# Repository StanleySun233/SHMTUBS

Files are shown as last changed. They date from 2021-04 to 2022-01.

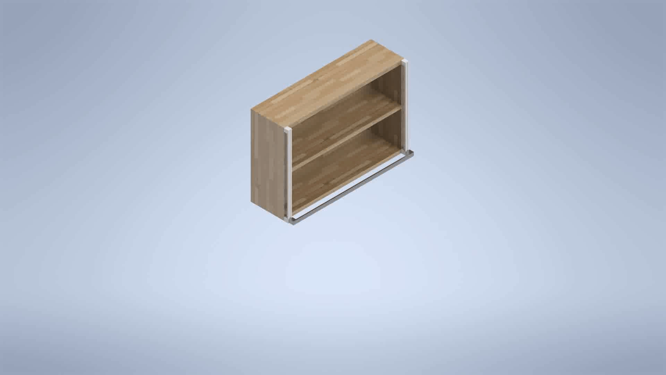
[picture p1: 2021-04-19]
3D-construction/视频/滑台移动.gif

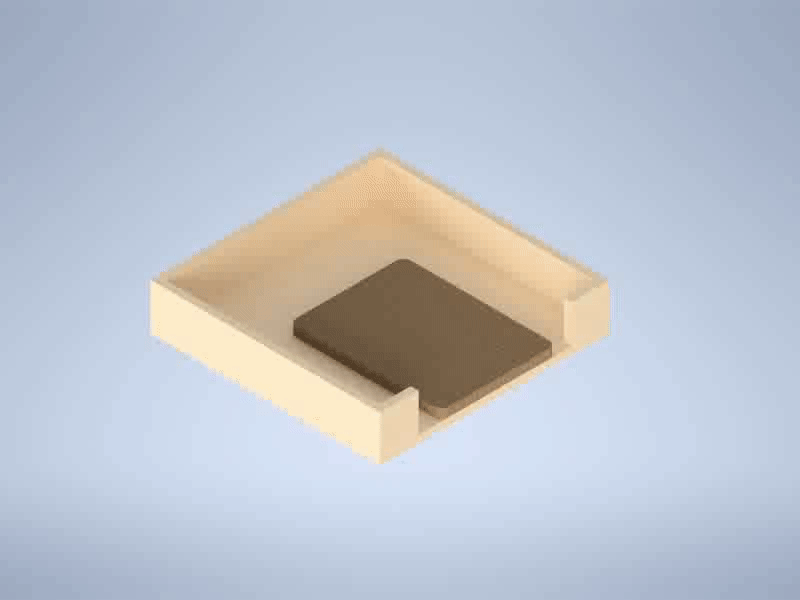
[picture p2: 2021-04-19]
3D-construction/视频/书本直立.gif

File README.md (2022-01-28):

# Robot For Book Sorting

## 简介

这个项目的代码起始于2021年度大学生创新创业训练计划项目。

## 主体

1. 将书本堆放在机器人上，重力感应器激活，进入工作状态。

2. 摄像头识别最上面的一本书。

3. 摄像头模块的单片机识别并转换条形码，输入到单片机主控。

4. WiFi模块连接到图书馆数据库，查找该条形码对应的图书所在的位置。

5. 找到相应的位置后，服务器传出位置信息，WiFi模块接受收数据。

6. 机械臂抓取最上面的图书，放到牵引臂上。

7. 横轴步进电机根据传回数据，向右运行厘米。

8. 纵轴步进电机根据传回数据，向上运行厘米。

9. 牵引臂推动图书进入指定位置。

10. 牵引臂返回到初始位置，重复运行程序，直至重力传感器检测到没有书籍。

## 寻迹：

1. 利用红外传感器，识别地面贴黑条区域和普通地面区域，黑色用1表示，普通地面用0表示。

2. 默认机器人初始在黑条区域，机器人前后左右配备四个红外传感器。

3. 如果单位时间监测区域均为1，那么传回信号，驱动小车直接向前走。

4. 如果单位时间某个方向的检测区不为1，那么通过算法设计传回信号，驱动小车转弯或者回退等操作。

## 涉及语言：C Python

涉及软件：`Arduino` , `Visual Studio` , `Pycharm`

## 参考

1. 循迹小车发布于 `BiliBili` 。

```
https://www.bilibili.com/video/BV1hm4y1Q77d/
```

2. 书本封面来自于开源数据集 `Book-30` 。

```
https://github.com/uchidalab/book-dataset
```

3. 机器学习来源于文章 `An evidential classifier based on Dempster-Shafer theory and deep learning` 的思路。

*目前暂未使用到 `Dempster-Shafer` ，准确率在83%*

```
https://github.com/tongzheng1992/E-CNN-classifier
```

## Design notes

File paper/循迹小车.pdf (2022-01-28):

学号：202010311229

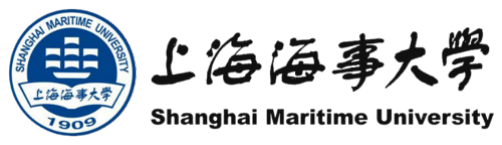
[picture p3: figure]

# 《计算机硬件课程设计》报告

学 | 院： 信息工程学院

专 业 名 称： 计算机科学与技术

班 | 级： 计算机 203
姓 | 名： 孙思进

指 导 教 师： 张琳

## 2021 年 12 月 23 日

《计算机硬件》课程设计报告

摘 要

为研究设计智能寻迹避障小车的控制部分, 文中通过研究超声波模块, 红外线

模块完成小车的控制。首先通过 Arduino 平台以及 Arduino IDE 软件进行程序编程

来控制小车的行驶。

寻迹小车由 MSP430 单片机模块、升压模块、电机驱动模块、红外光电传感器

等部分组成。小车能够沿着地面上的长宽为 1 cm 的黑白相间方格行驶, 并且可以

根据方格路径实现小车的自动寻迹功能, 小车在转弯处可自动减慢速度, 以避免由

于速度过快而偏离给定路线。当红外光电传感器阵列遇到长度为 5 cm, 宽度为 1cm

的黑色条纹的时候, 小车停车。

经过实验测试, 该自动寻迹小车能够较好的实现寻迹功能, 可被用在货物运输、

实验教学和玩具中。

关键词: 寻迹小车; 红外线; 单片机

Key words: Trace trolley; Infrared; Microcontroller

I

目 | 录
摘要 | I
1 任务安排 | 1
2 相关硬件说明 | 2
3 小车结构与系统模块设计 | 7
4 硬件电路设计 | 8
5 工作原理 | 9

II

6 测试 | 14
7 困难及解决方案 | 16

III

## 1 任务安排

表 1.1 人员任务安排

任务安排 | 人员

核心代码 孙思进、肖茗怡

图片视频 | 肖茗怡
代码优化 | 涂枭
文档编写 | 杨怡林、涂枭

## 2 相关硬件说明

### 2.1 Arduino 单片机

### 2.1.1 Arduino Uno 介绍

我们小组的 Arduino 的版本使用的是 Uno，Arduino Uno 是 ArduinoUSB 接 口系列的最新版本，作为 Arduino 平台的参考标准模板。UNO 的处理器核心是 ATmega328，同时具有 14 路数字输入/输出口（其中 6 路可作为 PWM 输出），6 路 模拟输入，一个 16MHz 晶体振荡器，一个 USB 口，一个电源插座，一个 ICSPheader 和一个复位按钮。

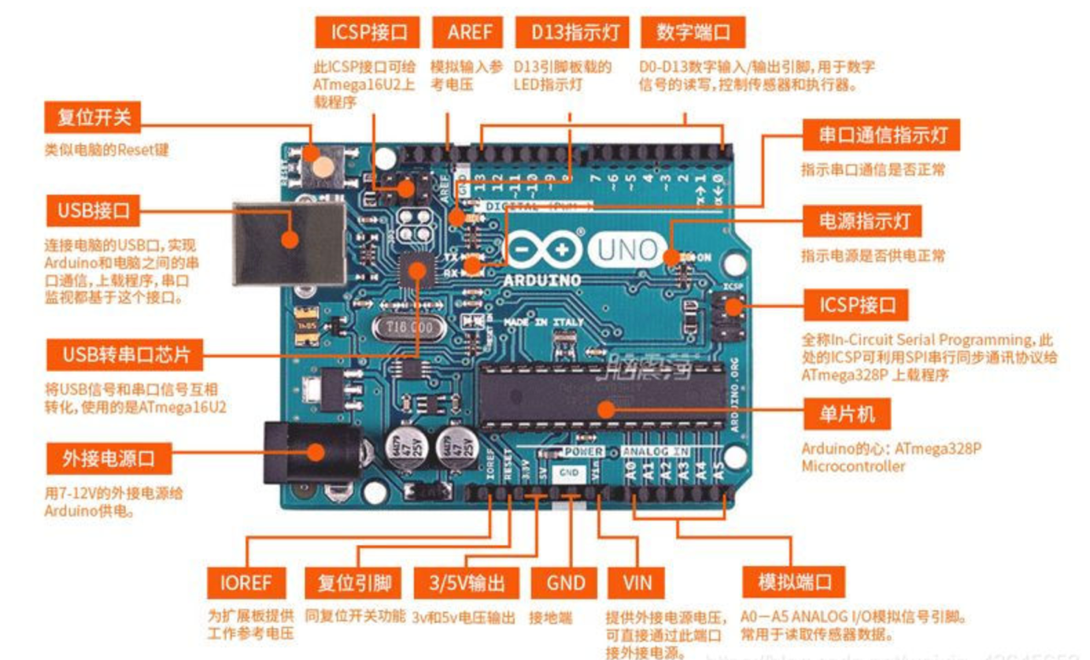
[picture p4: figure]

图 2.1 Arduino Uno 开发板

### 2.1.2 引脚介绍

- Power 引脚：开发板可提供 3.3V 和 5V 电压输出。
- Vin 引脚：可用于从外部电源为开发板供电。
- Analog In 引脚：模拟输入引脚，开发板可读取外部模拟信号，A0 A5 为模拟 输入引脚。
- Digital 引脚：UNO R3 拥有 14 个数字 I/O 引脚，其中 6 个可用于 PWM(脉宽 调制) 输出。

- TX 和 RX 引脚：标有 TX(发送) 和 RX(接收) 的两个引脚用于串口通讯。其中 标有 TX 和 RX 的 LED 灯连接相应引脚，在串口通讯时会以不同速度闪烁。
- 13 引脚：开发板标记第 13 引脚，连接板载 LED 灯，可通过控制 13 引脚来控 制 LED 灯亮灭。一般拿到开发板上电板载灯都会闪烁，可辅助检测开发板是 否正常。
- GND：在该项目中 GND 即为电源的负极，同时要保证 Arduino 开发板，驱动 模块等所有模块的 GND 连在一起才可以正常工作。

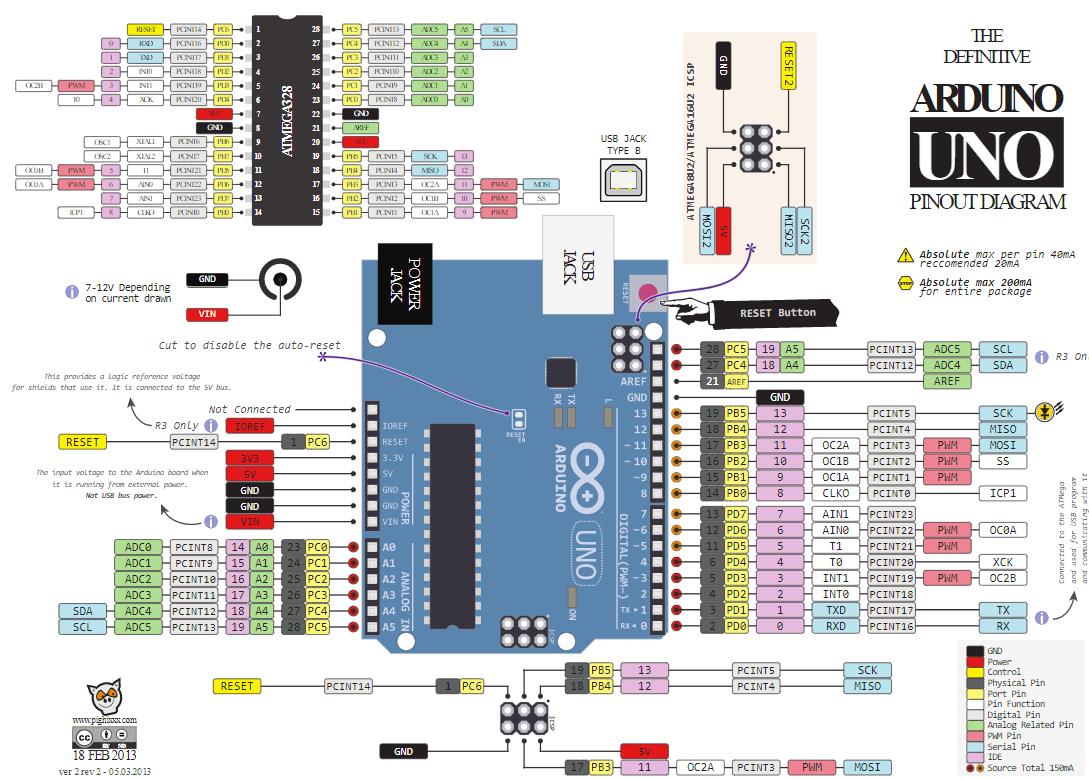
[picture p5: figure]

图 2.2 Arduino Uno 引脚分配图

### 2.1.3 端口介绍

Arduino Uno 有 6 个模拟引脚，它们作为 ADC（模数转换器）使用。这些引脚 用作模拟输入，但也可用作数字输入或数字输出。

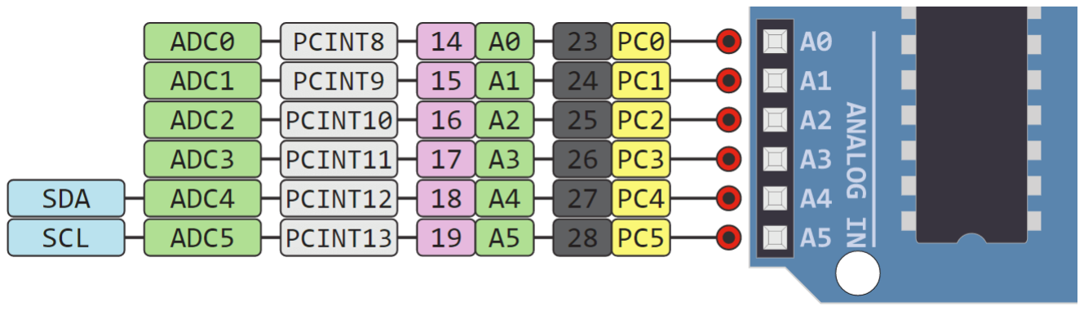
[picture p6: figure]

图 2.3 Arduino Uno 引脚分配 模拟输入

### 2.1.4 供电方式介绍

Arduino Uno 开发板可以使用三种方式供电，直流电源插孔、VIN 引脚以及 USB 电缆。在这里我们使用的是直流电源插孔的方式对其进行供电。 电源插孔通常连接到一个适配器，开发板的供电范围可以是 5-20V，但制造商 建议将其保持在 7-12V 之间。高于 12V 时，稳压芯片可能会过热，低于 7V 可能会 供电不足。这里我们使用老师提供的电池即可满足要求。

图 2.4 Arduino Uno 引脚分配 电源

### 2.2 红外收发模块

我们小组使用的是知道老师提供的 TCRT5000 红外传感器，TCRT5000 传感器 的红外发射二极管不断发射红外线，当发射出的红外线没有被反射回来或被反射 回来但强度不够大时，红外接收管一直处于关断状态。
此时模块的输出端为低电平，指示二极管一直处于熄灭状态，被检测物体出 现在检测范围内时，红外线被反射回来且强度足够大，红外接收管饱和，此时模块 的输出端为高电平，指示二极管被点亮。

### 2.2.1 模数转换

Arduino Uno 有 6 个模拟引脚，它们作为 ADC（模数转换器）使用。这些引脚 用作模拟输入，但也可用作数字输入或数字输出。
ADC 表示模拟到数字转换器。ADC 是用于将模拟信号转换为数字信号的电子 电路。模拟信号的这种数字表示允许处理器（其是数字设备）测量模拟信号并在 其操作中使用它。Arduino 引脚 A0-A5 能够读取模拟电压。

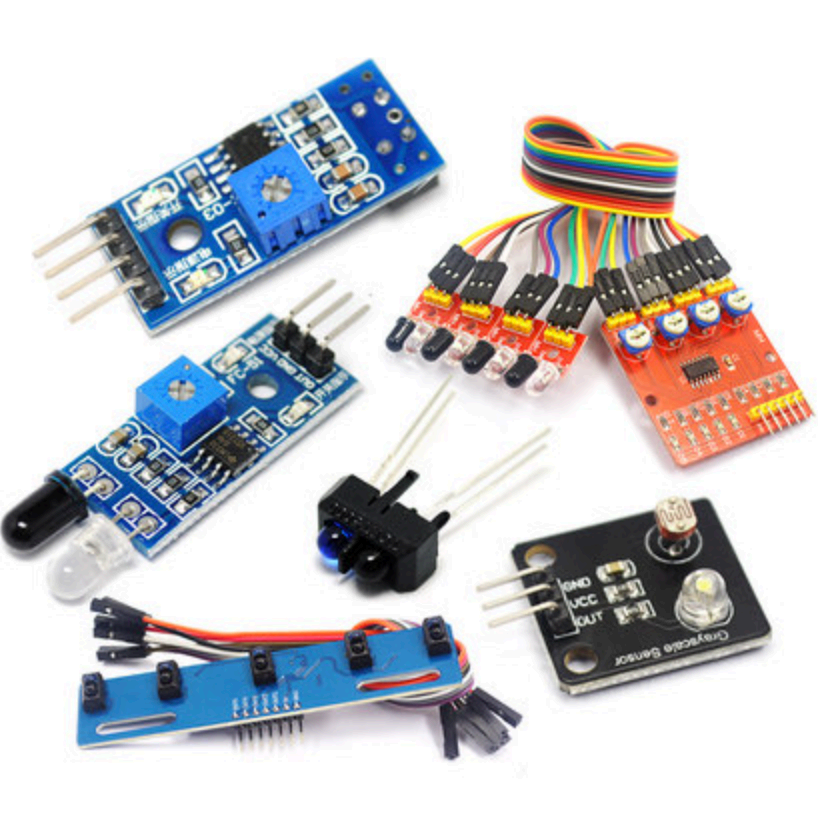
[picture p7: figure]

图 2.5 Arduino Uno 引脚分配 模拟输入

### 2.2.2 数字端口介绍

Arduino Uno 的引脚 0-13 用作数字输入/输出引脚。其中，引脚 13 连接到板载 的 LED 指示灯；引脚 3、5、6、9、10、11 具有 PWM 功能。 脉宽调制（PWM）是一种调制技术，用于将消息编码为脉冲信号。PWM 由两 个关键部分组成：频率和占空比。PWM 频率决定了完成单个周期（周期）所需的 时间以及信号从高到低的波动速度。占空比决定信号在总时间段内保持高电平的 时间。占空比以百分比表示。在 Arduino 中，支持 PWM 的引脚产生约 500Hz 的恒 定频率，而占空比根据用户设置的参数而变化。PWM 信号用于直流电机的速度控 制，调光 LED 等。

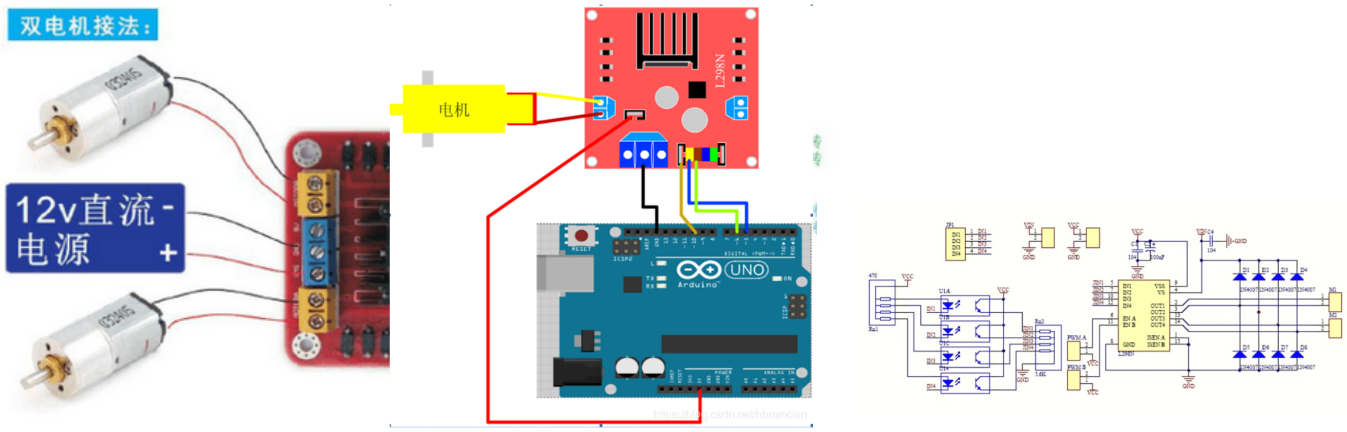
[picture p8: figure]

图 2.6 电机驱动 | 图 2.7 电机相连示意 | 图 2.8 L298N 的原理图

### 2.3 L298N 介绍

L298N 是一款接受高电压的电机驱动器，直流电机和步进电机都可以驱动，其 芯片工作电压：DC 4.5 5.5V，电机驱动电源电压 DC 5–35V。一片驱动芯片可同时

控制两个直流减速电机做不同动作，在 6V 到 46V 的电压范围内，提供 2 安培的 电流，并且具有过热自断和反馈检测功能。电源输入输出正常时有 LED 灯指示。 L298N 可对电机进行直接控制，通过主控芯片的 I/O 输入对其控制电平进行设定， 就可为电机进行正转反转驱动，操作简单、稳定性好，可以满足直流电机的大电流 驱动条件。

## 3 小车结构与系统模块设计

### 3.1 小车结构

如下图3.1所示，小车前方有三个红外收发模块用于检测路径；主体左部分上 放有 L298N 直流步进电机驱动模块，用于调节直流电机的转速；主体右部分放有 Arduino Uno 作为主控。有 9V 锂电池和 4 节 1.5V 干电池作为电源。左右两边分别 有两个直流电机分别调节左轮与右轮的转速。

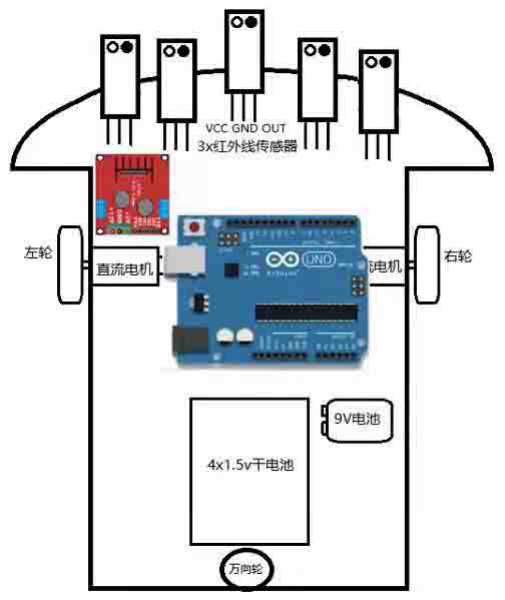
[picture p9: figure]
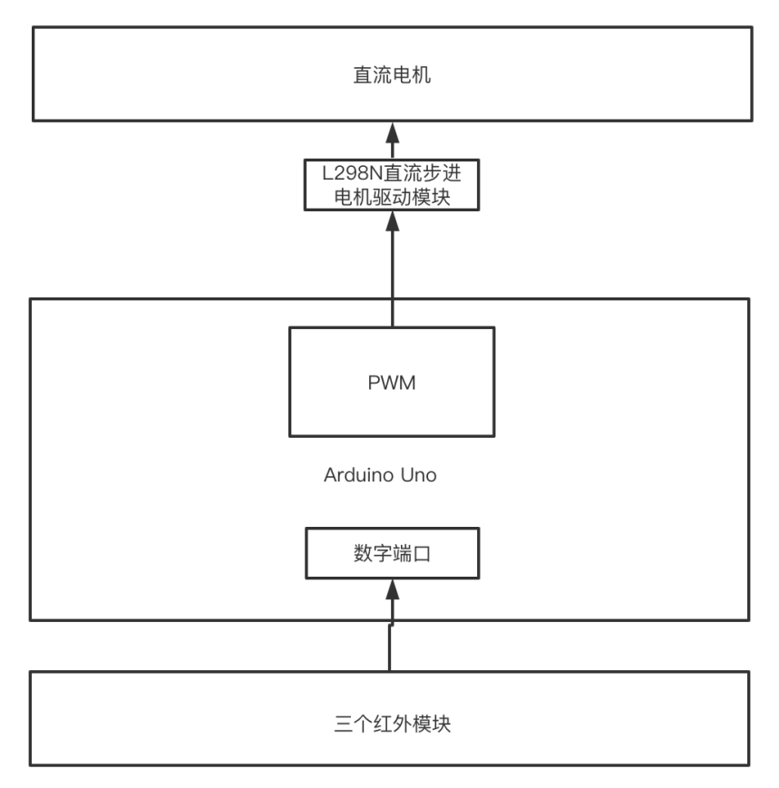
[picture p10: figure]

图 3.1 小车整体结构 | 图 3.2 系统模块

### 3.2 系统模块

如图3.2所示，Arduino Uno 通过数字端口接收三个红外收发模块的数据，通过 分析传来的数据，输出 PWM 数字信号到直流步进电机驱动模块，来控制左右电机 的转速。

## 4 硬件电路设计

### 4.1 电源

如图4.1所示，9v 充电电池接到直流步进电机的 9V 输入口，为直流电机供电， 同时接入 Arduino Uno 的 DC 插头，为开发版供电；5 个红外收发模块的 VCC 输入 口与电机的 +5V 输入口、ENA 输入口、ENB 输入口，接入到 Arduino Uno 的 +5V 输出口；5 个红外收发模块的 GND 输入口与电机的 GND 输入口接入到 Arduino Uno 的 GND 输出口上；两个直流电机的正负极分别接入到电机的马达 A 输出口 与马达 B 输出口上。

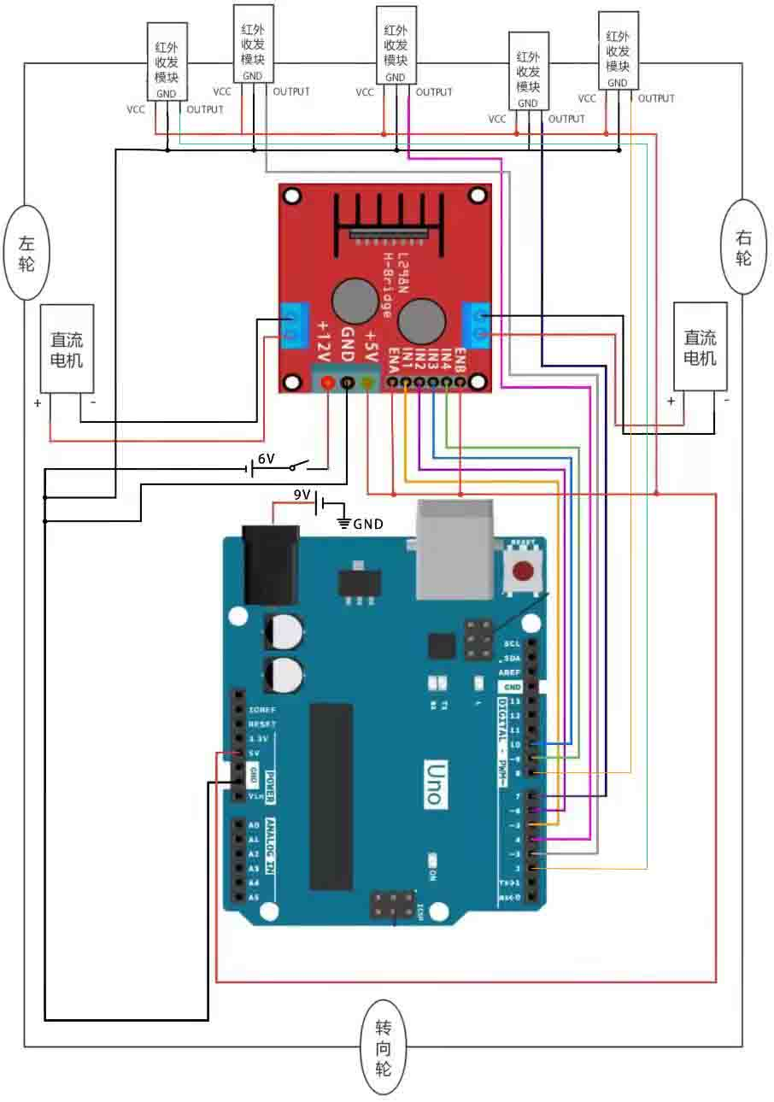
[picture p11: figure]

图 4.1 电路原理图

### 4.2 红外收发模块

如图4.1所示，将五个红外收发模块的 OUTPUT 输出口接入到 Arduino Uno 数 字输入口，向 Arduino Uno 实时传送检测到的数据。

### 4.3 直流步进电机驱动模块

如图4.1所示，将电机的输入口分别接入到 Arduino Uno 的带有 PWM 功能的 数字输出口上。Arduino Uno 通过分析红外收发模块传来的数据，通过上述端口控 制直流电机驱动模块，直流电机驱动模块再控制直流马达的转动。

## 5 工作原理

### 5.1 控制直流电机转动

Arduino 开发版的 5、6、10、9 号带有 PWM 功能的数字输出端口传递控制信 号到 L298N 控制电机转动。

1 | /* 电 机 引 脚 定 义 * /
2 | # d e f i n e moto r_L IN1 11
3 | # d e f i n e moto r_L IN2 10
4 | # d e f i n e motor_RIN1 3
5 | # d e f i n e motor_RIN2 9

6
7 | /* 引 脚 初 始 化 * /
8 | v oi d m ot o r _ pi n ( ) {
9 | pinMode ( motor_LIN1 , OUTPUT ) ;
10 | pinMode ( motor_LIN2 , OUTPUT ) ;
11 | pinMode ( motor_RIN1 , OUTPUT ) ;
12 | pinMode ( motor_RIN2 , OUTPUT ) ;
13 | }
14 | /* 左 大 转 弯 * /
15 | v oi d t u r n _ 1 _ l e f t ( ) {
16 | a n al o gW rit e ( motor_LIN1 , 0 ) ;
17 | a n al o gW rit e ( motor_LIN2 , 0 ) ;
18 | a n al o gW rit e ( motor_RIN1 , 1 0 0 ) ;
19 | a n al o gW rit e ( motor_RIN2 , 0 ) ;
20 | }
21 | /* 左 小 转 弯 * /
22 | v oi d t u r n _ 2 _ l e f t ( ) {
23 | a n al o gW rit e ( motor_LIN1 , 0 ) ;
24 | a n al o gW rit e ( motor_LIN2 , 0 ) ;
25 | a n al o gW rit e ( motor_RIN1 , 6 0 ) ;
26 | a n al o gW rit e ( motor_RIN2 , 0 ) ;
27 | }

28 | v oi d t u r n _ l e f t 9 0 ( ) {
29 | a n al o gW rit e ( motor_LIN1 , 0 ) ;
30 | a n al o gW rit e ( motor_LIN2 , 1 0 0 ) ;
31 | a n al o gW rit e ( motor_RIN1 , 1 0 0 ) ;
32 | a n al o gW rit e ( motor_RIN2 , 0 ) ;
33 | }

34
35 | /* 右 大 转 弯 * /
36 | v oi d t u r n _ 1 _ r i g h t ( ) {
37 | a n al o gW rit e ( motor_LIN1 , 1 0 0 ) ;
38 | a n al o gW rit e ( motor_LIN2 , 0 ) ;
39 | a n al o gW rit e ( motor_RIN1 , 0 ) ;
40 | a n al o gW rit e ( motor_RIN2 , 0 ) ;
41 | }

42
43 | /* 右 小 转 弯 * /
44 | v oi d t u r n _ 2 _ r i g h t ( ) {
45 | a n al o gW rit e ( motor_LIN1 , 6 0 ) ;
46 | a n al o gW rit e ( motor_LIN2 , 0 ) ;
47 | a n al o gW rit e ( motor_RIN1 , 0 ) ;
48 | a n al o gW rit e ( motor_RIN2 , 0 ) ;
49 | }
50 | v oi d t u r n _ r i g h t 9 0 ( ) {
51 | a n al o gW rit e ( motor_LIN1 , 1 0 0 ) ;
52 | a n al o gW rit e ( motor_LIN2 , 0 ) ;
53 | a n al o gW rit e ( motor_RIN1 , 0 ) ;
54 | a n al o gW rit e ( motor_RIN2 , 1 0 0 ) ;
55 | }
| motor 函数可直接控制左右两个直流电机的转动，如 motor(-240，120) 代表左
| 轮反转，右轮正转，240 经 PWM 后可调节左轮反转的速度，120 经 PWM 后可交
| 接右轮正转速度。

### 5.2 读入红外收发模块信号

| 为了保证小车判断的稳定性，我们使用五个红外模块，以下是代码定义。
1 | /* 寻 迹 模 块 从 左 到 右 * /

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

### 5.3 行驶

### 5.3.1 红外线检测状态

其中“1”表示检测到黑线，“0”代表没有检测到黑线。

表 5.1 小车状态示意图

Sensor1 Sensor2 Sensor3 Sensor4 Sensor5 | 小车状态
0 | 0 | 0 | 1 | 1 | 左转 90 度
1 | 1 | 0 | 0 | 0 | 右转 90 度
0 | 1 | 1 | 1 | 1 | 左大转弯
0 | 0 | 1 | 1 | 1 | 左大转弯补充状态
1 | 0 | 1 | 1 | 1 | 左小转弯
1 | 0 | 0 | 1 | 1 | 直行补充状态
1 | 1 | 0 | 1 | 1 | 直行
1 | 1 | 1 | 0 | 1 | 右小转弯
1 | 1 | 0 | 1 | 1 | 直行补充状态
1 | 1 | 1 | 1 | 0 | 右大转弯
1 | 1 | 1 | 0 | 0 | 右大转弯补充状态
0 | 0 | 0 | 0 | 0 | 停止

### 5.3.2 直行

如表5.1所示，当且仅当红外模块 3 检测到路径时小车直行。

1 | /* 直 行 * /
2 | v oi d f o r w a r d ( ) {
3 | a n al o gW rit e ( motor_LIN1 , 1 0 0 ) ;
4 | a n al o gW rit e ( motor_LIN2 , 0 ) ;

5 | a n al o gW rit e ( motor_RIN1 , 1 0 0 ) ;
6 | a n al o gW rit e ( motor_RIN2 , 0 ) ;
7 | }

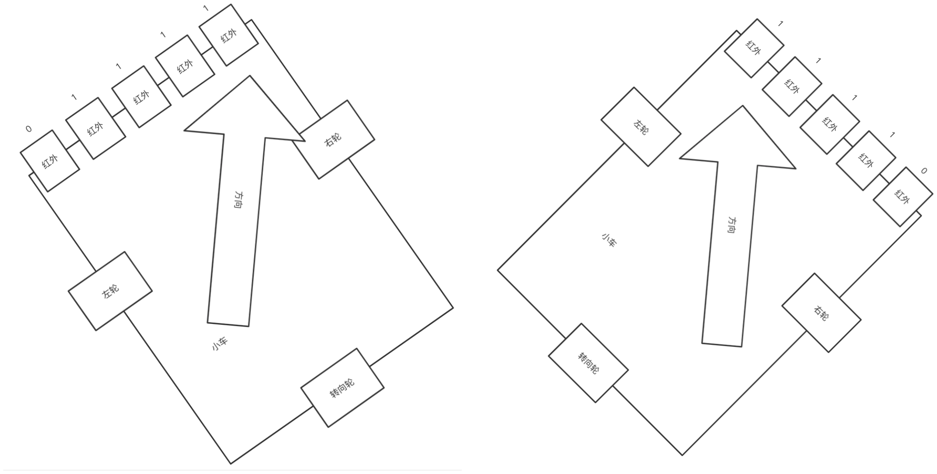
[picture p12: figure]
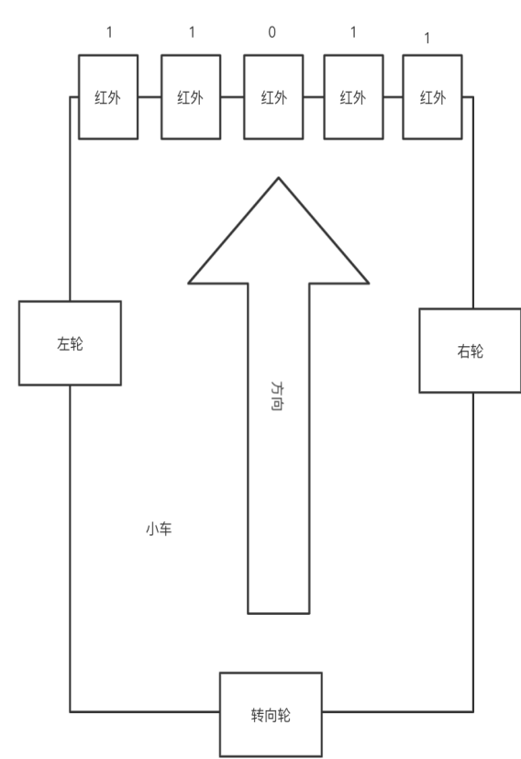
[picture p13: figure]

图 5.1 直行示意图 | 图 5.2 向左转示意图 | 图 5.3 向左转示意图

### 5.3.3 向左转

如图5.2所示，当只有红外模块 1 检测到路径时，小车向左调整直到红外模块 2 检测到路径。

1 | e l s e i f ( ( d a t a [ 0 ] == 0 ) && ( d a t a [ 1 ] == 1 ) && ( d a t a [ 2 ]
| == 1 ) && ( d a t a [ 3 ] == 1 ) && ( d a t a [ 4 ] == 1 ) )
2 | e r r o r = −2;

### 5.3.4 向右转

如图5.3所示，当红外模块 5 检测到路径时，小车向右调整直到红外模块 3 检 测到路径。

1 | e l s e i f ( ( d a t a [ 0 ] == 1 ) && ( d a t a [ 1 ] == 1 ) && ( d a t a [ 2 ]
| == 1 ) && ( d a t a [ 3 ] == 1 ) && ( d a t a [ 4 ] == 0 ) )
2 | e r r o r = 2 ;

### 5.3.5 停止

当只有红外模块 1、2、3、4、5，同时检测到无路径时，小车会保持原状，如 果同时检测到有路径时，会停止当前状态，表示到达终点。

1 | e l s e i f ( ( d a t a [ 0 ] == 0 ) && ( d a t a [ 1 ] == 0 ) && ( d a t a [ 2 ]
| == 0 ) && ( d a t a [ 3 ] == 0 ) && ( d a t a [ 4 ] == 0 ) )
2 | e r r o r = 5 ;

### 5.4 程序流

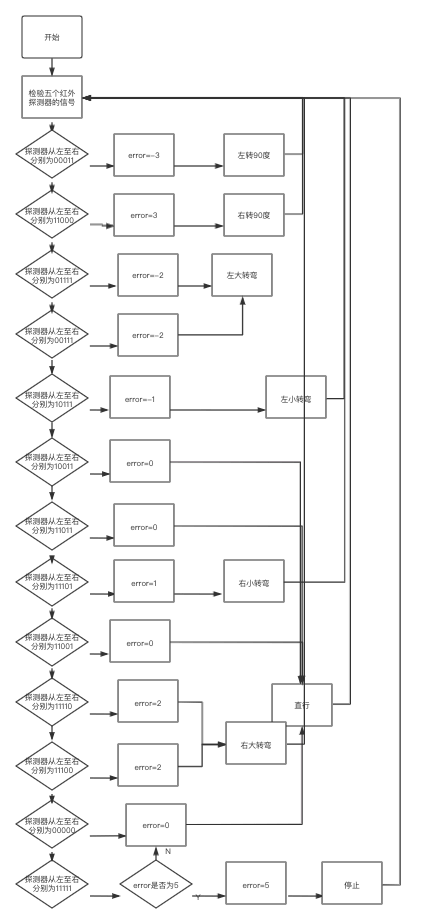
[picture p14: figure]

图 5.4 电路原理图

## 6 测试

### 6.1 调试和装配

1) 首先尝试用 PIC12F683 来控制小车的前进、后退、左右转向。结果试验成功， 小车能正常的跑动起来。成功检测小车的机械性能可以达到我们预期的目的。
2) 制作主板
3) 主板通电前检查：电路安装完毕，我们首先直观检查电路各部分生产线是否 正确，检查电源、地线、信号线、元器件引脚之间有无短路，器件有无接错。 结果发现 L298N 芯片的 5 和 12 管脚没有接地，查看发现原来是原理图没注 意改正才导致的。
4) 通电检查：给电机通电，观察电机是否工作正常。电机正常工作时，后驱工作 电流为 320 mA，电压为 5.4V；前驱电机工作电流为 180mA，电压为 5.41V。 给主板通电，观察电路各部分器件有无异常现象。
5) 主板安装调试（主控芯片用 PIC16F886），在调试的过程中我们发现了原理图 中有一个小小的错误。这个错误导致小车的稳压芯片过热。一起讨论之后决 定，修改原理图，调换小车驱动芯片的位置。改动之后，小车电源稳压芯片过 热现象消失。小车也能实现了基本的功能。（由于我们没能在制板之前发现这 个问题，导致了主板在修整后变得不太美观了。）
6) 制作并调试小车循迹板，传感器采用反射式红外传感器 ST178，当 Vcc=5V 时， 工作电流为 17mA,VR1=3.83V,VD=1.17V,RD=68.8 欧。

### 6.2 软件修复

在调试的过程中却发现小车不循迹，经过了很长的努力，终于发现了问题的 所在，原来是代码控制逻辑写错了导致（错将判断条件为真当成为假使用的来用）。 改正后调试，终于实现了循迹功能。

### 6.3 测试总结

测试结果表明：本组智能小车能很好的完成了基本功能和循迹功能，跑道是由 黑色胶布在白色地面上拉线完成，小车可以从 O 型跑道的任何段为起点，跑完全 程。本组智能小车目前只能完成在没有任何交叉路口的跑道上，要想跑在有“十”

字路口的跑道上，还须要对循迹程序进行补充和修改。我们保留了各种硬件接口 和软件子程序接口，方便以后的扩展和进一步的开发。

## 7 困难及解决方案

1) 小车走得过慢或者有的弯不能贴合指定路线。
烧入电机控制的小程序有的指令用的不正确，导致电路功能不能完全实现，另 外软件程序中的延时有的过长、有的过短。
2) 红外无法检测旁边的障碍物。
将小车舵机上的红外设置为八字形。首先八字形具有一定的美观效果，再者， 可以避免设置成一字型撞到障碍物，最后就是可以使小车在行走的时候同时 也能检测旁边的障碍物。
3) 在十字路口或者岔路口前进的时候小车会失去方向。 通过后续代码的优化，在十字路口或者岔路口时，小车会首先直走。

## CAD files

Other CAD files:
3D-construction/OldVersions/书.0002.ipt
3D-construction/OldVersions/书架.0002.ipt
3D-construction/OldVersions/外置架.0002.ipt
3D-construction/OldVersions/放书的.0003.ipt
3D-construction/OldVersions/水平滑台.0009.ipt
3D-construction/OldVersions/水平滑盖.0003.ipt
3D-construction/OldVersions/滑盖上.0008.ipt
3D-construction/OldVersions/竖直滑台.0011.ipt
3D-construction/书.ipt
3D-construction/书架.ipt
3D-construction/外置架.ipt
3D-construction/放书的.ipt
3D-construction/水平滑台.ipt
3D-construction/水平滑盖.ipt
3D-construction/滑盖上.ipt
3D-construction/竖直滑台.ipt
3D-construction/部件/OldVersions/书架装上滑台.0012.iam
3D-construction/部件/OldVersions/滑台.0004.iam
3D-construction/部件/OldVersions/部件1.0007.iam
3D-construction/部件/书架装上滑台.iam
3D-construction/部件/滑台.iam
3D-construction/部件/部件1.iam

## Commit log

2021-04-19 This is
    [书.0002.ipt, 书.ipt, 书架.0002.ipt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]
2022-01-28 update: update first checkpoint
    [书.0002.ipt, 书.ipt, 书架.0002.ipt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]
